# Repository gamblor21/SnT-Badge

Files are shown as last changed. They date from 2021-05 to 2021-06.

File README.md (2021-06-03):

# As Seen on Show & Tell Badge

This is a PCB badge based on the Adafruit sticker that (pre-covid) would be sent to community members who appeared on their Show and Tell show.

The badge is in the shape and style of the original sticker and made in the FeatherWing format with duel header rows (though single could likely fit).

The front has 6 Neopixels (connected to D5) and a light sensor (hooked to A0). The back has an IMU the ICM-20602 (ICM-20608-G can be used as a drop-in replacement). The IMU is hooked up via I2C.

The source folder has sample code and a basic CircuitPython driver for the ICM-20602 but is far from a full implementation.

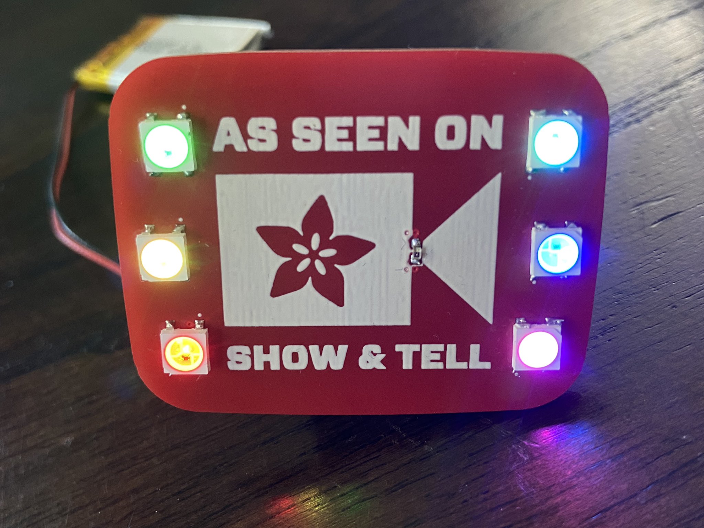
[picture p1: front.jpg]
FrontPCB


OSHW_FACTS

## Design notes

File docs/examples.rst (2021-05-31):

Simple tests
------------

Ensure your device works with these simple tests.

.. literalinclude:: ../src/code.py
    :caption: src/code.py
    :linenos:

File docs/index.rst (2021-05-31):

.. include:: ../README.md

Table of Contents
=================

.. toctree::
    :maxdepth: 4
    :hidden:

    self

.. toctree::
    :caption: Examples

    examples

.. toctree::
    :caption: API Reference
    :maxdepth: 3

    api

.. toctree::
    :caption: Other Links

    Download <https://github.com/gamblor21/SnT-Badge>
    CircuitPython Reference Documentation <https://circuitpython.readthedocs.io>

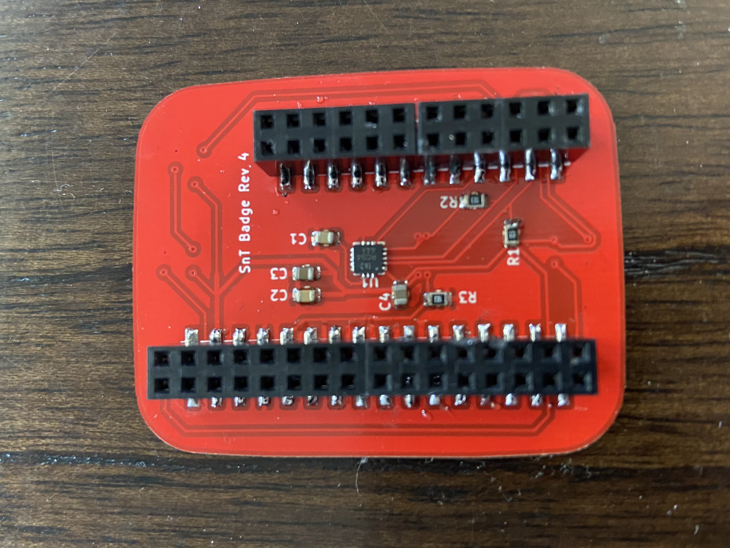
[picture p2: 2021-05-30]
back.jpg

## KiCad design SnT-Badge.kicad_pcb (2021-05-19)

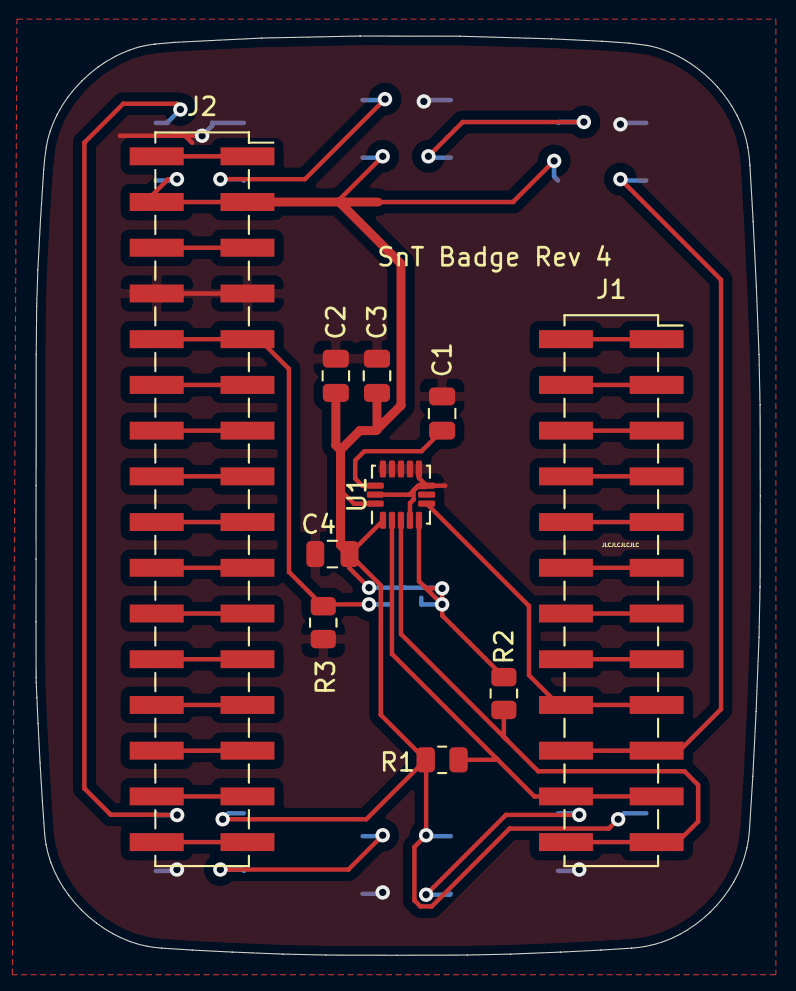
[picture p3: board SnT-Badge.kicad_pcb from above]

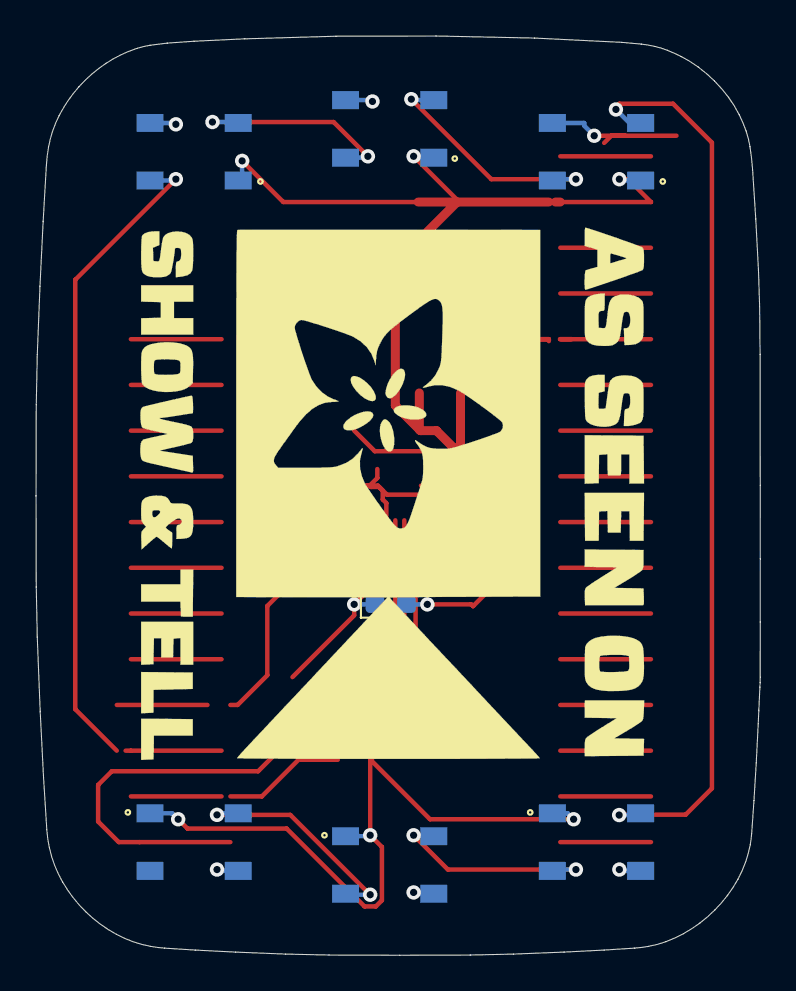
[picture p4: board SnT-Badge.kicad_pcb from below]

Board: 2 copper layers, 40.2 x 51.1 mm, 17 parts (7 on the bottom side), 34 nets.

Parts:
C1, C2: 0.1uF; C_0805_2012Metric
C3: 2.2uF; C_0805_2012Metric
C4: 10nF; C_0805_2012Metric
D1: SK6812; LED_SK6812_PLCC4_5.0x5.0mm_P3.2mm
D2, D3, D4, D5, D6: WS2812B; LED_WS2812B_PLCC4_5.0x5.0mm_P3.2mm
D7: D_Photo; D_0603_1608Metric_Pad1.05x0.95mm_HandSolder
J1: Conn_02x12_Row_Letter_Last; PinSocket_2x12_P2.54mm_Vertical_SMD
J2: Conn_02x16_Row_Letter_Last; PinSocket_2x16_P2.54mm_Vertical_SMD
R1, R2, R3: 10k; R_0805_2012Metric
U1: ICM-20602; LGA-16_3x3mm_P0.5mm_LayoutBorder3x5y

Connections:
3VDC: C2.1, C3.1, C4.1, D1.3, D2.1, D3.1, D4.1, D5.1, D6.1, D7.1, J2.3, J2.4, R1.2, R2.2, U1.1, U1.5, U1.16
GND: C1.2, C2.2, C3.2, C4.2, D1.1, D2.3, D3.3, D4.3, D5.3, D6.3, J2.7, J2.8, R3.1, U1.4, U1.8, U1.9, U1.10, U1.11, U1.12, U1.13, U1.15
INT: J1.17, J1.18, U1.6
LEDs: D1.2, J1.19, J1.20
LIGHT: D7.2, J2.9, J2.10, R3.2
unnamed: D1.4, D2.4
unnamed: D2.2, D3.4
unnamed: D3.2, D4.4
unnamed: D4.2, D5.4
unnamed: D5.2, D6.4
unnamed: J1.1, J1.2
unnamed: J1.3, J1.4
unnamed: J1.5, J1.6
unnamed: J1.7, J1.8
unnamed: J1.9, J1.10
unnamed: J1.11, J1.12
unnamed: J1.13, J1.14
unnamed: J1.15, J1.16
unnamed: J2.1, J2.2
unnamed: J2.5, J2.6
unnamed: J2.11, J2.12
unnamed: J2.13, J2.14
unnamed: J2.15, J2.16
unnamed: J2.17, J2.18
unnamed: J2.19, J2.20
unnamed: J2.21, J2.22
unnamed: J2.23, J2.24
unnamed: J2.25, J2.26
unnamed: J2.27, J2.28
unnamed: J2.29, J2.30
unnamed: J2.31, J2.32
REGOUT: C1.1, U1.14
SCL: J1.21, J1.22, R1.1, U1.2
SDA: J1.23, J1.24, R2.1, U1.3

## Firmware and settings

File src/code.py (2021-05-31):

import time
import board
import analogio
import neopixel
import supervisor
import math
from ICM20602 import ICM20602
from adafruit_led_animation.animation.rainbowcomet import RainbowComet

supervisor.set_rgb_status_brightness(0)
ADDRESS = 0x68

i2c = board.I2C()

pixels = neopixel.NeoPixel(board.D5, 6, brightness = 0.1, auto_write = False)
pixels.fill((0, 0, 0))
pixels.show()

rainbow_comet = RainbowComet(pixels, speed=0.1, tail_length=6, bounce = False)

imu = ICM20602(i2c, 0x68)
light = analogio.AnalogIn(board.A0)

pos = 0
nextPrint = time.monotonic()+0.3

while True:
    acc = imu.acceleration

    if time.monotonic() > nextPrint:
        print(imu.gyro)
        print(acc)
        print(light.value)
        nextPrint += 0.3

    if acc[2] < -4.1: #-8.3:
        if light.value > 3000:
            pixels[0] = (150,0,0)
            pixels[1] = (150,150,0)
            pixels[2] = (0,150,0)
            pixels[3] = (0,150,150)
            pixels[4] = (0,0,150)
            pixels[5] = (150,0,150)
            pixels.show()
            pass
        else:
            rainbow_comet.animate()

    elif abs(acc[0]) > 3.0:
        pixels.fill((0,0,0))
        x = acc[0]
        if x < -3.5:
            pixels[0] = (0,0,50)
        if x < -5.5:
            pixels[1] = (0,50,0)
        if x < -7.7:
            pixels[2] = (50,0,0)
        if x > 3.5:
            pixels[5] = (0,0,50)
        if x > 5.5:
            pixels[4] = (0,50,0)
        if x > 7.7:
            pixels[3] = (50,0,0)

        pixels.show()
    else:
        pixels.fill((0,0,0))
        pixels.show()

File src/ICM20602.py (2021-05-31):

"""

`src.ICM20602`
====================================================

"""


import adafruit_bus_device.i2c_device as i2c_device

def twos_comp(val, bits):
    """compute the 2's complement of int value val"""
    if (val & (1 << (bits - 1))) != 0: # if sign bit is set e.g., 8bit: 128-255
        val = val - (1 << bits)        # compute negative value
    return val


class ICM20602:
    """
    Main Show and Tell Badge

    :param ~busio.I2C i2c: The I2C bus the device is connected to.
    :param int addr: Show and Tell Address. Defaults to :const:`0x68`

    """

    _BUFFER = bytearray(6)

    def __init__(self, i2c, addr):
        self._sensor = i2c_device.I2CDevice(i2c, addr)
        print("Initializing")
        self._write_u8(0x6B, 0x01) #self._sensor.write(b'\x6B\x01')
        print("Config")
        self._write_u8(0x1A, 0x01) #self._sensor.write(b'\x1A\x01')

    @property
    def gyro(self):
        """
        The raw gyro sensor values.
        A 3-tuple of X, Y, Z axis values
        """
        xhigh = self._read_u8(0x43)
        xlow = self._read_u8(0x44)

        valx = xhigh << 8 | xlow
        valx = twos_comp(valx, 16)
        valx = valx / 131

        yhigh = self._read_u8(0x45)
        ylow = self._read_u8(0x46)

        valy = yhigh << 8 | ylow
        valy = twos_comp(valy, 16)
        valy = valy / 131

        zhigh = self._read_u8(0x47)
        zlow = self._read_u8(0x48)

        valz = zhigh << 8 | zlow
        valz = twos_comp(valz, 16)
        valz = valz / 131

        return (valx, valy, valz)

    @property
    def acceleration(self):
        """
        The raw acceleration sensor values.
        A 3-tuple of X, Y, Z axis values
        """
        xhigh = self._read_u8(0x3b)
        xlow = self._read_u8(0x3c)

        yhigh = self._read_u8(0x3d)
        ylow = self._read_u8(0x3e)

        zhigh = self._read_u8(0x3f)
        zlow = self._read_u8(0x40)

        valx = xhigh << 8 | xlow
        valx = twos_comp(valx, 16)
        valx = valx / 16384 * 9.8

        valy = yhigh << 8 | ylow
        valy = twos_comp(valy, 16)
        valy = valy / 16384 * 9.8

        valz = zhigh << 8 | zlow
        valz = twos_comp(valz, 16)
        valz = valz / 16384 * 9.8

        return (valx, valy, valz)

    def _read_u8(self, address):
        with self._sensor as i2c:
            self._BUFFER[0] = address & 0xFF
            i2c.write_then_readinto(
                self._BUFFER, self._BUFFER, out_end=1, in_start=1, in_end=2
            )
        return self._BUFFER[1]

    def _read_bytes(self, address, count, buf):
        with _self.sensor as i2c:
            buf[0] = address & 0xFF
            i2c.write_then_readinto(buf, buf, out_end=1, in_end=count)

    def _write_u8(self, address, val):
        with self._sensor as i2c:
            self._BUFFER[0] = address & 0xFF
            self._BUFFER[1] = val & 0xFF
            i2c.write(self._BUFFER, end=2)

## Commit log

2021-05-23 Adding ICM20602 driver
2021-05-30 Added front and back images of finished board
2021-05-30 Added BOM
